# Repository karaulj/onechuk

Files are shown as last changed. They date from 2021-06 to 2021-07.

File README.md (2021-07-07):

# onechuk
A modded-out Nintendo Wii Nunchuk controller with an ESP32 running machine learning (Tensorflow Lite for Microcontrollers) on joystick commands.

The one nunchuk that can do it all: onechuk.

## Main features
- Single RGB LED for readouts
- Multiple action mapping sets
  - Admin (Red): Restart, Enter deep sleep, Get BLE status, accelerometer/joystick debug
  - BLE HID (Green): Pause/Play, Prev/Next Track, Volume Up/Down, Start BLE pairable window
- Built-in LiPo w/ charging unit (charge via micro USB port)
- Automatically enters deep sleep if inactive for 60 seconds to conserve battery
- Wake up from deep sleep by tapping micro USB port

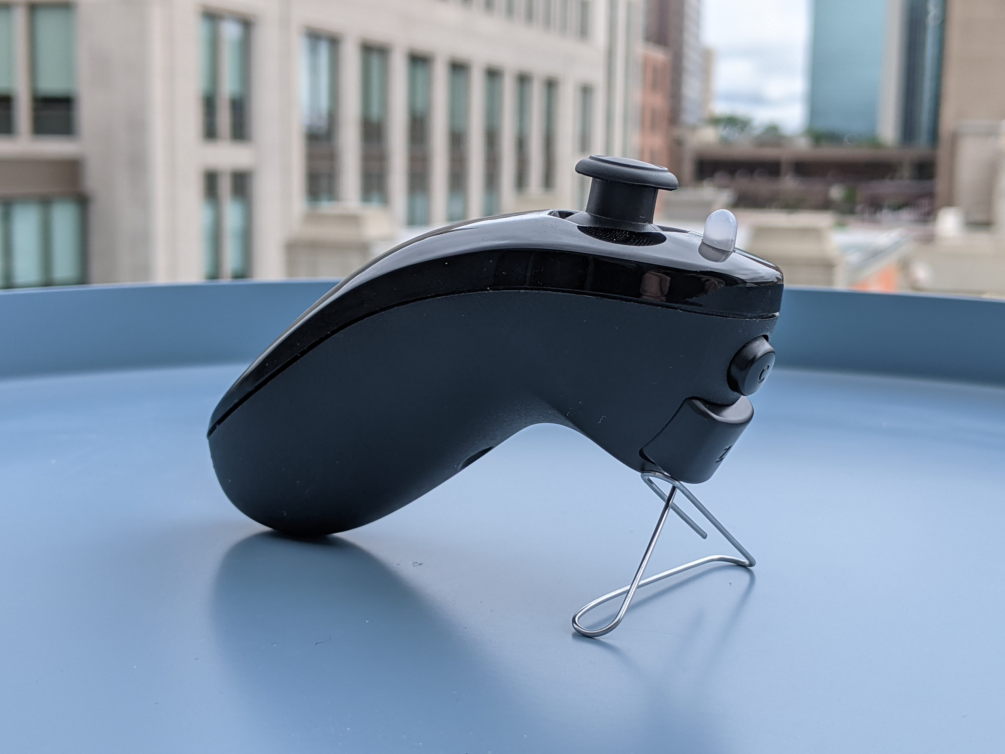
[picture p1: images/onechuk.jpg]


Deep sleep wakeup by tapping micro USB port

## Compiling
This project is built using [ESP-IDF](https://docs.espressif.com/projects/esp-idf/en/latest/esp32/get-started/). You can use the VSCode extension, Eclipse plugin or the typical CLI commands yourself:
```
idf.py build
idf.py -p <port> flash
```

## Overview

### Boot modes
Like a computer, onechuk has multiple boot modes. Also like a computer, you select the boot mode by holding down certain keys at startup.

### Device Mode (Tensorflow)
Device mode is the default boot mode. It allows the user to make joystick commands by holding down the "Z" button and drawing some shape with the joystick. Upon releasing the "Z" button, inference is performed on the drawn shape and if the probability is high enough, the action is executed. The current command can be ignored by pressing the "C" button mid-gesture.

There are multiple action mapping sets allowed, called "device profiles". A device profile is nothing more than a class with a series of logically linked callback functions. The action that gets performed depends on which device profile is active; a circle gesture on the BLE HID device profile will make it pairable, while a circle gesture on the admin profile will restart the ESP32. Same gesture, multiple possible actions.

You can cycle through device profiles by pressing the "C" button.



### Training Mode
Training mode sends raw joystick data over UART to a connected PC. You can boot into training mode by holding down the "C" button during startup. Once the LED flashes orange after the init sequence, training mode has been entered.

#### Collecting training data
Training data collection is made simple by running the `training/collect_training_data.py` script. Make joystick gestures as you normally would (hold down "Z" button and draw) and press "Enter" to delete the last sample. Data is automatically saved to the `training/data` directory when you exit the program. There are some pre-trained gestures:
- Circle
- Left flick
- Right flick
- Up flick
- Down flick
- Center click

I've found that ~200 samples/gesture is more than plenty. By default 25% of the collected data is reserved for validation. This can be modified with the `--pct_test_data` argument.



#### Training the model
The model is trained by running the `training/train_model.py` script. Three model files are written to the `training/output` directory:
- `gesture_model.tflite`: standard TFLite model
- `gesture_model_tflite.cc`: model as C array
- `gesture_model_tflite.h`: header for C array model

The latest model files are automatically copied from the `training/output` directory at compile time. Collect, train, compile, done. The model performs very well, often topping 99% for probability:

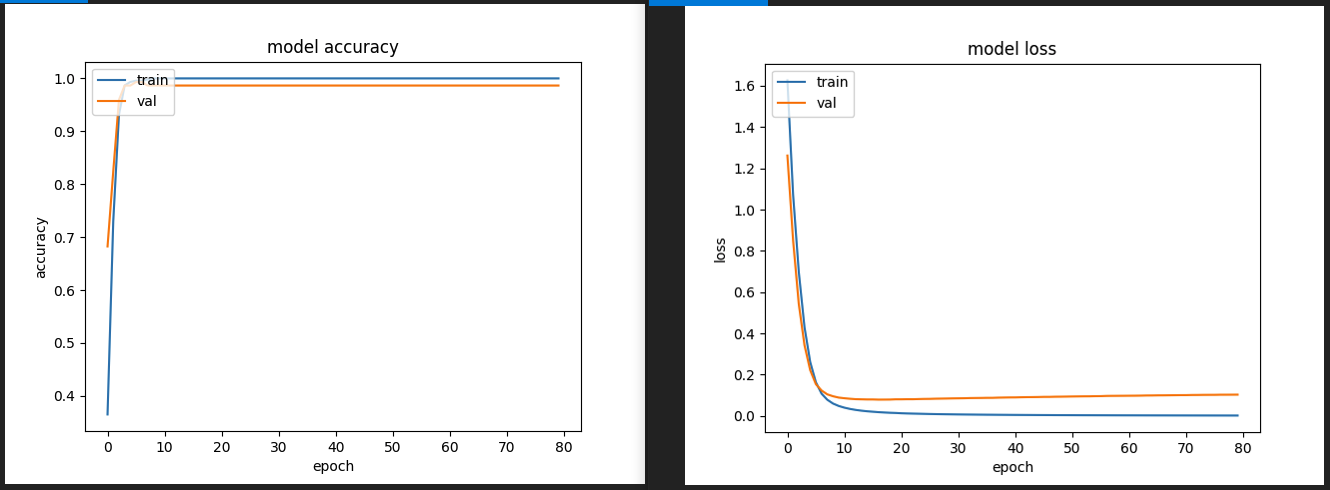
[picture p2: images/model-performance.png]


_**NOTE: The training script uses the xxd unix command to generate the C files and will fail using Windows' Command Prompt.**_ One solution is to use [WSL](https://docs.microsoft.com/en-us/windows/wsl/install-win10) as a shell and install xxd through `sudo apt install xxd`. 

## Construction
The physical construction process is briefly described here.

### Parts List
- [Nunchuk controller](https://www.amazon.com/Nintendo-Nunchuk-Controller-Black-Wii-U/dp/B0094X1ZXU/) (original Nintendo version)
- [TinyPICO Nano](https://www.tinypico.com/tinypico-nano) ESP32 development board
- [400mAh LiPo Battery](https://www.adafruit.com/product/3898) 
- [RGB LED](https://www.amazon.com/EDGELEC-Tri-Color-Multicolor-Diffused-Resistors/dp/B077XGF3YR/) (pack of 100)
- [Micro USB connector](https://www.adafruit.com/product/1829)
- ["Wire Wrap"](https://www.adafruit.com/product/1446)

### CAD
The micro USB port housing is a friction-fit 3D-printed piece. Use CA to glue the micro USB connector to the housing, then friction-fit the housing into the nunchuk. If CA gets on the front of the connector and prevents touches from registering, lightly scrape it off with an exacto knife.

CAD files can be found in the `CAD` folder.

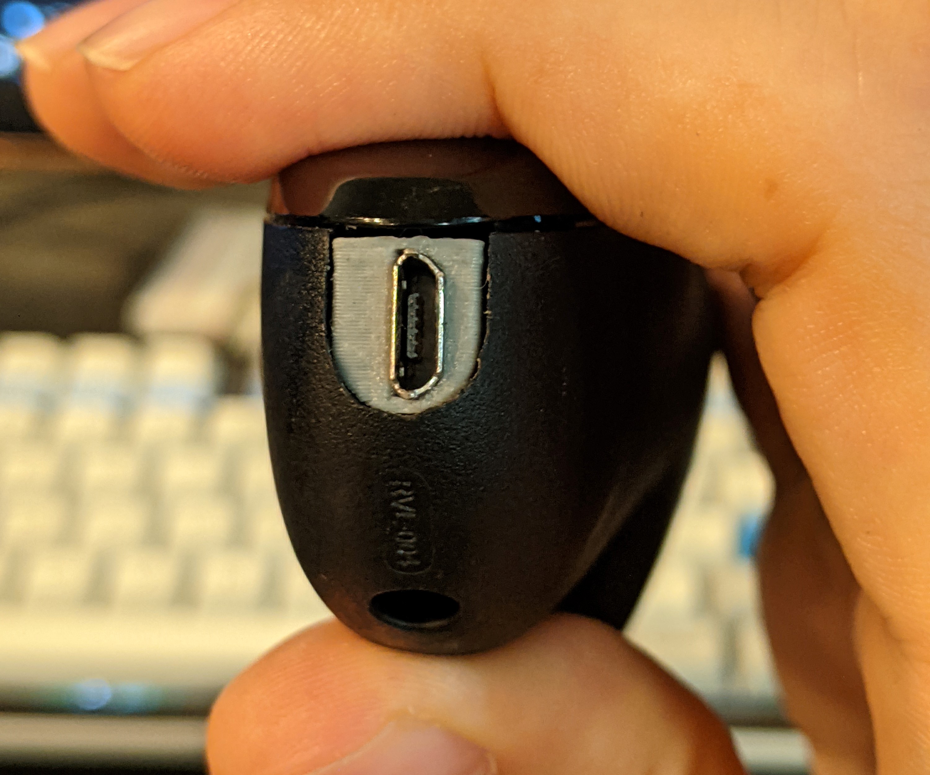
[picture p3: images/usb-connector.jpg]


### Original vs. knockoff nunchuks
Initially I planned on using a cheap nunchuk clone instead of one sold by Nintendo, given their outrageous prices. It became clear that the analog joystick quality on the cheap knockoff was so poor that data couldn't be shared between a knockoff and an original nunchuk, at which point I broke down and got an original. All data collected using an original, Nintendo, "real" nunchuk is prefixed with an "r", in case I decide to go back and collect gesture data using a "fake" nunchuk at some point.

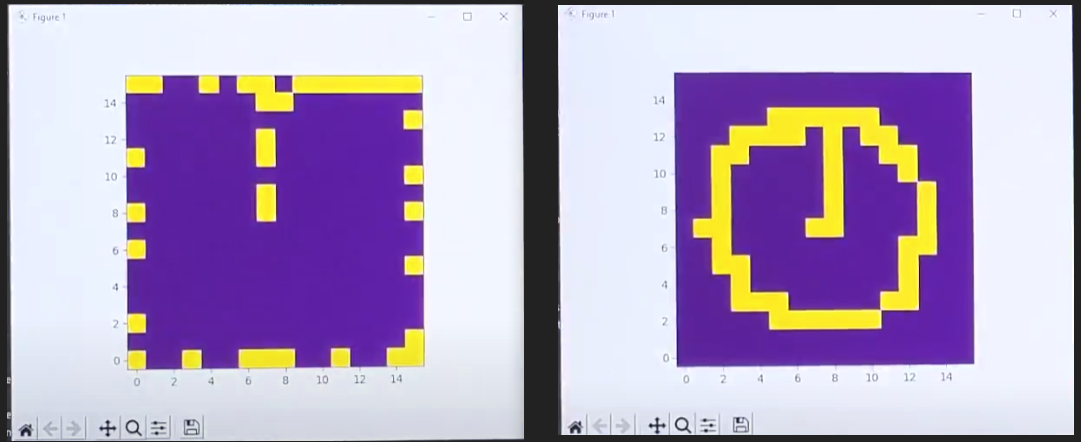
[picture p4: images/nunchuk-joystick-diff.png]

The circle gesture on knockoff (left) vs. original (right) nunchuks

### Fitting everything in
Nunchuks can have a decent amount of interior space if you clear out the excess support material. This can be done with a pair of flush cutters and some high-grit sandpaper:

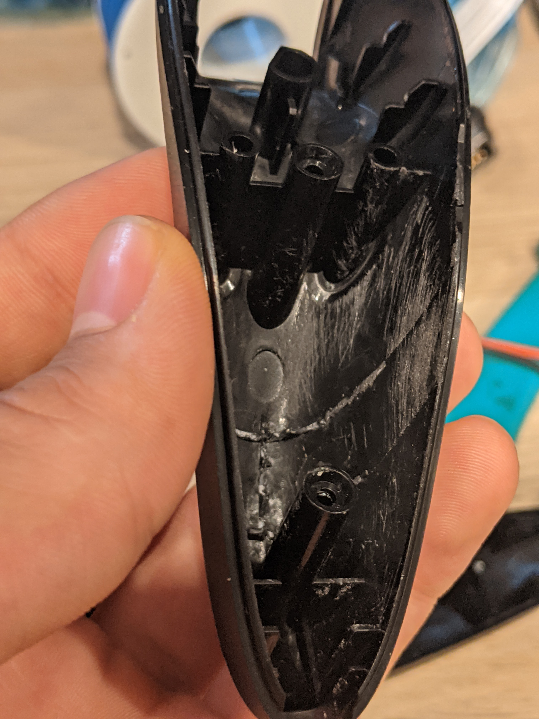
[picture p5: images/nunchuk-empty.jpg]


Then it's just a matter of soldering and assembly:

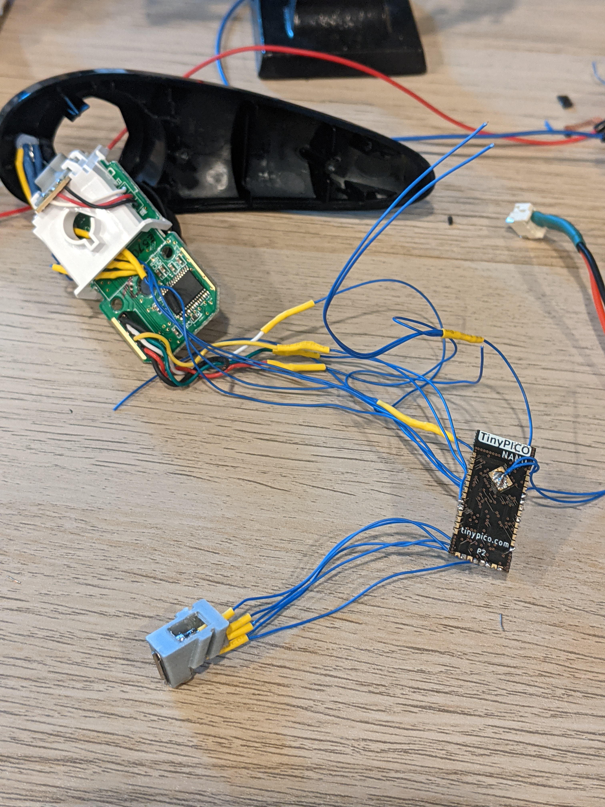
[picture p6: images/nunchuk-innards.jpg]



## Acknowledgements
Inspired by https://github.com/jakkra/Gesture-Detecting-Macro-Keyboard. Some code (especially for training) is modified and reused.

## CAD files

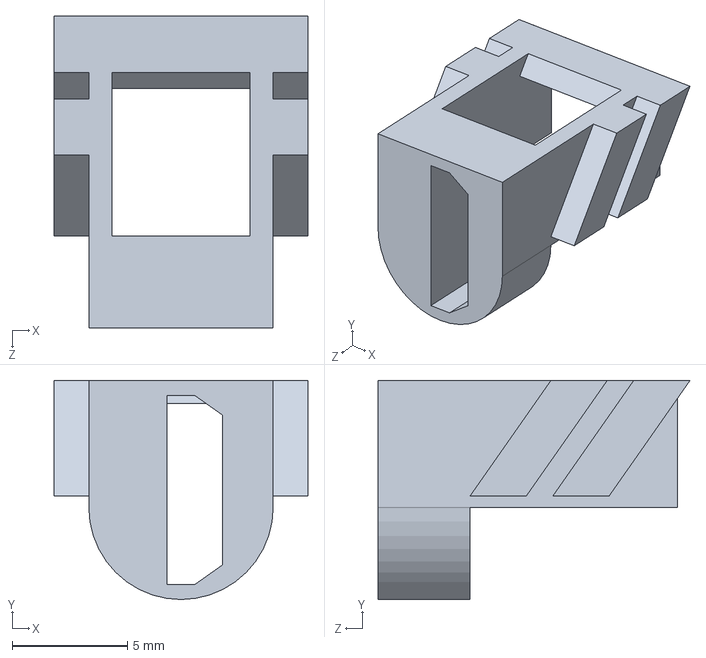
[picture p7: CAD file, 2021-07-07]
CAD/nunchuk_usb_housing.SLDPRT
11.0 x 9.50 x 13.5 mm

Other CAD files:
CAD/nunchuk_usb_housing.STL

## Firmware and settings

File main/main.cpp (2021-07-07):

/*
 * main.cpp
 * 
 *  Onechuk main program file.
 *
 *  Created on: Jun 11, 2021
 *      Author: Jacob
 */

#include "settings.h"
#include "tasks.h"
#include "queues.h"

#include <stdio.h>
#include "sdkconfig.h"
#include "freertos/FreeRTOS.h"
#include "freertos/task.h"
#include "freertos/queue.h"
#include "esp_log.h"
// i2c
#include "hal/gpio_types.h"
#include "hal/i2c_types.h"
#include "driver/i2c.h"
// ble
#include "ble_utils.h"
// touch/sleep
#include "driver/touch_pad.h"
#include "esp_sleep.h"
// main components
#include "NunchukController.h"
#include "RGB_CC_LED.h"
#include "TinyPICO.h"
#include "rgb_commands.h"
#include "BLE_HID.h"

static const char *TAG = "main";

extern "C" void app_main(void);


static void i2cInit()
{
    i2c_config_t i2cConfig;
	i2cConfig.mode = I2C_MODE_MASTER;
	i2cConfig.scl_io_num = I2C_SCL_PIN;
	i2cConfig.sda_io_num = I2C_SDA_PIN;
	i2cConfig.scl_pullup_en = GPIO_PULLUP_ENABLE;
	i2cConfig.sda_pullup_en = GPIO_PULLUP_ENABLE;
	i2cConfig.clk_flags = 0;
	i2cConfig.master.clk_speed = I2C_FREQ_HZ;
	ESP_ERROR_CHECK(i2c_param_config(I2C_PORT_NUM, &i2cConfig));
	ESP_ERROR_CHECK(i2c_driver_install(I2C_PORT_NUM, I2C_MODE_MASTER, 0, 0, 0));
}


static void touchInit()
{
    ESP_ERROR_CHECK(touch_pad_init());
    ESP_ERROR_CHECK(touch_pad_set_fsm_mode(TOUCH_FSM_MODE_TIMER));

    // from ESP IDF deep sleep example
    // Set reference voltage for charging/discharging
    // In this case, the high reference valtage will be 2.4V - 1V = 1.4V
    // The low reference voltage will be 0.5
    // The larger the range, the larger the pulse count value.
    ESP_ERROR_CHECK(touch_pad_set_voltage(TOUCH_HVOLT_2V4, TOUCH_LVOLT_0V5, TOUCH_HVOLT_ATTEN_1V));
    ESP_ERROR_CHECK(touch_pad_config(DEEP_SLEEP_TOUCH_PAD_NUM, 0));

    // calibrate touch pad - don't touch during init
    int avg = 0;
    const size_t calibration_count = 128;
    for (int i = 0; i < calibration_count; ++i) {
        uint16_t val;
        touch_pad_read(DEEP_SLEEP_TOUCH_PAD_NUM, &val);
        avg += val;
    }
    avg /= calibration_count;
    const int min_reading = 300;
    if (avg < min_reading) {
        ESP_LOGW(TAG, "Touch pad #%d average reading too low for deep sleep setup: %d",
            DEEP_SLEEP_TOUCH_PAD_NUM, avg
        );
        ESP_ERROR_CHECK(touch_pad_config(DEEP_SLEEP_TOUCH_PAD_NUM, 0));
    } else {
        int threshold = avg - 100;
        ESP_LOGI(TAG, "Touch pad #%d threshold set to %d", DEEP_SLEEP_TOUCH_PAD_NUM, threshold);
        ESP_ERROR_CHECK(touch_pad_config(DEEP_SLEEP_TOUCH_PAD_NUM, threshold));
    }
    ESP_ERROR_CHECK(esp_sleep_enable_touchpad_wakeup());
    ESP_ERROR_CHECK(esp_sleep_pd_config(ESP_PD_DOMAIN_RTC_PERIPH, ESP_PD_OPTION_ON));
}


void app_main(void)
{
    /*
     *  SYSTEM INIT
     */
    // queues - init done at compile time, check status now
    queuesCheck();

    // peripherals init - configure in settings.h
	i2cInit();
    touchInit();

    // main component classes init
    TinyPICO* tinypico = TinyPICO::getInstance();
    RGB_CC_LED mainLED = RGB_CC_LED(R_PIN, G_PIN, B_PIN);
    NunchukController* nunchuk = NunchukController::getInstance(I2C_PORT_NUM);

    // get init params from nunchuk buttons
    nunchuk->fetchLatestReadings();
    uint8_t cButtonPressed = nunchuk->getCButton();
    uint8_t zButtonPressed = nunchuk->getZButton();
    enum task_init_t {
        INIT_MODE_NULL,
        INIT_MODE_TRAINING,
        INIT_MODE_DEVICE
    } initType;
    if (cButtonPressed && !zButtonPressed) {            // C-button: training mode
        ESP_LOGI(TAG, "TRAINING mode selected");
        initType = INIT_MODE_TRAINING;
    } else if (!cButtonPressed && !zButtonPressed) {    // default: device mode
        ESP_LOGI(TAG, "DEVICE mode selected");
        initType = INIT_MODE_DEVICE;
    } else {
        ESP_LOGI(TAG, "no mode selected");
        initType = INIT_MODE_NULL;
    }

    // system init cplt
    xQueueSend(ledCmdQueue, (void*)&RGB_CMD_INIT, 1/portTICK_PERIOD_MS);


    /*
     *  TASKS INIT
     */
    // basic I/O tasks
    xTaskCreate(&touchDeepSleepTask, TOUCH_DEEP_SLEEP_TASK, 2048,
        NULL, tskIDLE_PRIORITY, &touchDeepSleepTaskHandle);
    xTaskCreate(&ledCmdTask, LED_CMD_TASK, 2048,
        (void*)&mainLED, tskIDLE_PRIORITY, &ledCmdTaskHandle);  // min priority
    xTaskCreate(&nunchukReadTask, NUNCHUK_READ_TASK, 4096,
        NULL, tskIDLE_PRIORITY, &nunchukReadTaskHandle);        // min priority
    
    switch (initType) {

    // training mode sends joystick values over serial if Z button pressed
    case INIT_MODE_TRAINING:
        xQueueSend(ledCmdQueue, (void*)&RGB_CMD_TRAINING_MODE, 1/portTICK_PERIOD_MS);
        xTaskCreate(&trainingModeTask, TRAINING_MODE_TASK, 4096,
            NULL, 12, &trainingModeTaskHandle);                 // med priority
        break;

    // device mode (default) performs actions from joystick gesture commands
    case INIT_MODE_DEVICE:
        bleInit();
        xQueueSend(ledCmdQueue, (void*)&RGB_CMD_DEVICE_MODE, 1/portTICK_PERIOD_MS);
        xTaskCreate(&joystickCmdTask, JOYSTICK_CMD_TASK, 4096,
            NULL, 12, &joystickCmdTaskHandle);	                // med priority
        xTaskCreate(&joystickInferenceTask, JOYSTICK_INFERENCE_TASK, 65536,
            NULL, 24, &joystickInferenceTaskHandle);	        // max priority
        break;

    case INIT_MODE_NULL:
        break;
    }


    // Run Forrest, run
    while(true)
    {
        vTaskDelay(1000 / portTICK_PERIOD_MS);
    }
}

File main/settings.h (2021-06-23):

/*
 * settings.h
 * 
 *  All relevant user settings.
 *
 *  Created on: Jun 11, 2021
 *      Author: Jacob
 */

#ifndef MAIN_SETTINGS_H_
#define MAIN_SETTINGS_H_

#include "freertos/FreeRTOS.h"
#include "driver/touch_pad.h"


// I2C
#define I2C_SDA_PIN                 21
#define I2C_SCL_PIN                 22
#define I2C_FREQ_HZ                 100000
#define I2C_PORT_NUM                0

// nunchuk
#if configTICK_RATE_HZ > 100
#define NUNCHUK_READ_RATE_HZ        500
#else
#define NUNCHUK_READ_RATE_HZ        100
#endif

// RGB LED
#define R_PIN                       25
#define G_PIN                       26
#define B_PIN                       27

// touch
#define DEEP_SLEEP_TOUCH_PAD_NUM    TOUCH_PAD_NUM6
#define DEEP_SLEEP_DELAY_SEC        60

// TF Lite Micro
#define INPUT_SHAPE_DIM             16
#define INPUT_PRESCALER             16      // INPUT_SHAPE_DIM*INPUT_PRESCALER = 256


#endif /* MAIN_SETTINGS_H_ */

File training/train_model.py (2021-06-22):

import tensorflow as tf
import numpy as np
from tensorflow.keras.utils import to_categorical
#from tensorflow import keras
from tensorflow.keras.models import Sequential
from tensorflow.keras.layers import Input
from tensorflow.keras.layers import Conv2D
from tensorflow.keras.layers import MaxPooling2D
from tensorflow.keras.layers import Dense
from tensorflow.keras.layers import Flatten
#from keras.optimizers import SGD
from tensorflow.keras.optimizers import SGD

from matplotlib import pyplot as plt
import os
from pathlib import Path
import argparse


INPUT_DIM = 16


train_dir = os.path.dirname(os.path.realpath(__file__)) + "/data"
output_dir = os.path.dirname(os.path.realpath(__file__)) + "/output"


def create_img_from_line(line):
	line = line.replace(' ', '')
	line = line.replace('\'', '')
	line = line.replace('"', '')
	line = line.replace('[', '')
	line = line.replace(']', '')
	line = line.replace('\n', '')
	line = line.split(',')
	img = np.zeros((INPUT_DIM, INPUT_DIM))
	for i in range(0, len(line), 2):
		img[max(0, int(line[i + 1]) - 1), max(0, int(line[i]) - 1)] = 1
	
	
	img = img.reshape(1, INPUT_DIM, INPUT_DIM, 1)
	img = img.astype('float32')
	return img

def load_manual_dataset():
	files = os.listdir(train_dir)
	num_gestures = len(files) / 2
	print("Found files {0} => {1} gestures".format(files, num_gestures))
	trainX = []
	testX = []
	trainY = []
	testY = []
	file_index = 0
	gestures = {}

	# Assumes the train/test data folder is not modified by user.
	# It should be generated using collect_train_data.py
	for file_name in files:
		gesture_name = file_name.split('.')[0]
		if (gesture_name not in gestures):
			gestures[gesture_name] = len(gestures)

		gesture_id = gestures[gesture_name]

		if (file_name.endswith('.train')):
			train_file = open(train_dir + '/' + file_name, "r")
			train_lines = train_file.readlines()

			for line in train_lines:
				trainX.append(create_img_from_line(line))
				trainY.append(gesture_id)

		elif file_name.endswith('.test'):
			test_file = open(train_dir + '/' + file_name, "r")
			test_lines = test_file.readlines()

			for line in test_lines:
				testX.append(create_img_from_line(line))
				testY.append(gesture_id)
		
	trainX = np.array(trainX)
	trainY = np.array(trainY)
	testX = np.array(testX)
	testY = np.array(testY)

	trainX = trainX.reshape((trainX.shape[0], INPUT_DIM, INPUT_DIM, 1))
	testX = testX.reshape((testX.shape[0], INPUT_DIM, INPUT_DIM, 1))
	
	print('Done creating test and train matrices')
	print(len(testX), len(testY))
	print(len(trainX), len(trainY))
	print(gestures)

	trainY = to_categorical(trainY)
	testY = to_categorical(testY)
	return trainX, trainY, testX, testY, gestures

# define CNN model
def define_model(num_gestures):
	model = Sequential()
	model.add(Input(shape=(INPUT_DIM, INPUT_DIM, 1)))
	model.add(Conv2D(8, (3, 3), activation='relu', kernel_initializer='he_uniform'))
	model.add(MaxPooling2D((2, 2)))
	model.add(Conv2D(16, (3, 3), activation='relu', kernel_initializer='he_uniform'))
	#model.add(Conv2D(16, (3, 3), activation='relu', kernel_initializer='he_uniform'))
	model.add(MaxPooling2D((2, 2)))
	model.add(Flatten())
	model.add(Dense(16, activation='relu', kernel_initializer='he_uniform'))
	model.add(Dense(num_gestures, activation='softmax'))
	# compile model
	opt = SGD(lr=0.001, momentum=0.9) # TODO Experiment with lr if needed, does not look like it right now
	model.summary()
	model.compile(optimizer=opt, loss='categorical_crossentropy', metrics=['accuracy'])
	return model
 
if __name__ == "__main__":
	parser = argparse.ArgumentParser(description='Create and store training data')
	
	args = parser.parse_args()
	# Create folder for the generated files
	Path(output_dir).mkdir(parents=True, exist_ok=True)
	print('create', output_dir)
	trainX, trainY, testX, testY, gesture_map = load_manual_dataset()
	print('Loaded train data shape is {0} and test data shape is {1}'.format(trainX.shape, testX.shape))

	# define model
	model = define_model(len(gesture_map))
	#model.load_weights('good_model_weights.h5')
	# fit model
	history = model.fit(trainX, trainY, epochs=80, batch_size=10, verbose=1, validation_data=(testX, testY))
	model.save_weights('good_model_weights.h5')

	plt.plot(history.history['accuracy'])
	plt.plot(history.history['val_accuracy'])
	plt.title('model accuracy')
	plt.ylabel('accuracy')
	plt.xlabel('epoch')
	plt.legend(['train', 'val'], loc='upper left')

	plt.figure()
	plt.plot(history.history['loss'])
	plt.plot(history.history['val_loss'])
	plt.title('model loss')
	plt.ylabel('loss')
	plt.xlabel('epoch')
	plt.legend(['train', 'val'], loc='upper left')
	plt.show()
	# save model
	model.save(output_dir + '/tf_gesture_model.h5')

	# Convert the model to Tensorflow Lite format.
	converter = tf.lite.TFLiteConverter.from_keras_model(model)
	tflite_model = converter.convert()

	# Save the model.
	with open(output_dir + '/gesture_model.tflite', 'wb') as f:
		f.write(tflite_model)
	
	# Convert to C++ file
	#print("xxd -i {0}/gesture_model.tflite > {0}/gesture_model_tflite.cc".format(output_dir))
	res = os.system("xxd -i {0}/gesture_model.tflite > {0}/gesture_model_tflite.cc".format(output_dir))
	#input() # command had to be manually entered, Enter resumes program
    
	# Rename the model, xxd gives it a name that contains the directory path also make the model const
	cppModelFileContentLines = []
	with open(output_dir + '/gesture_model_tflite.cc', 'r') as f:
		cppModelFileContentLines = f.readlines()
	os.remove(output_dir + '/gesture_model_tflite.cc') # Remove original c++ model
	cppModelFileContentLines[0] = 'const unsigned char gesture_model_tflite_data[] = {\n' # rename the large byte array containing the model
	cppModelFileContentLines.insert(0, '#include "gesture_model_tflite.h"\n')
	with open(output_dir + '/gesture_model_tflite.cc', 'w') as f: # create the fixed c++ model
		f.writelines(cppModelFileContentLines)
	
	# Create header file to access generated model
	# Append to the header file the map between TF result and the actual gesture
	with open(output_dir + '/gesture_model_tflite.h', 'w') as f:
		f.write('/*\nThis is a automatically generated TensorFlow Lite model by train_model.py, see README.md for more info.\nIt is converted into a C data array using xxd and is defined in gesture_model_tflite.cc\n*/\n')
		f.write('#ifndef TENSORFLOW_LITE_GESTURE_MODEL_H_\n')
		f.write('#define TENSORFLOW_LITE_GESTURE_MODEL_H_\n')

		f.write('extern const unsigned char gesture_model_tflite_data[];\n')

		# Generate enum with all labels
		f.write('\ntypedef enum gesture_label_t \n{\n')
		for idx, key in enumerate(gesture_map.keys()):
			f.write('\tLABEL_{0} = {1},\n'.format(key.upper(), idx))
		f.write('\tLABEL_END\n')
		f.write('} gesture_label_t;\n')

		f.write('\n')
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

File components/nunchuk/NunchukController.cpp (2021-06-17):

/*
 * NunchukController.cpp
 *
 *  Created on: Jun 11, 2021
 *      Author: Jacob
 */

#include "NunchukController.h"

#include <stdio.h>

#include "driver/i2c.h"
#include "hal/i2c_types.h"
#include "esp_log.h"
#include "esp_err.h"

static const char *TAG = "NunchukController";

// for nunchuk I2C data 
static volatile uint8_t nunchukBuffer[NUNCHUK_CONTROLLER_BUFFER_SZ];


NunchukController* NunchukController::nunchuk = nullptr;


NunchukController* NunchukController::getInstance(i2c_port_t i2cPort, uint8_t i2cAddr)
{
	if (nunchuk == nullptr)
	{
		nunchuk = new NunchukController(i2cPort, i2cAddr);
	}
	return nunchuk;
}


NunchukController::NunchukController(i2c_port_t i2cPort, uint8_t i2cAddr
    ) : port(i2cPort), addr(i2cAddr)
{
    // initialize, disable encryption
    i2c_cmd_handle_t cmd = i2c_cmd_link_create();
    i2c_master_start(cmd);
    i2c_master_write_byte(cmd, (addr<<1) | I2C_MASTER_WRITE, true);
    i2c_master_write_byte(cmd, 0xF0, true);
    i2c_master_write_byte(cmd, 0x55, true);
    i2c_master_write_byte(cmd, 0xFB, true);
    i2c_master_write_byte(cmd, 0x00, true);
    i2c_master_stop(cmd);
    i2c_master_cmd_begin(port, cmd, 10/portTICK_PERIOD_MS);
    i2c_cmd_link_delete(cmd);

    // fetch once
    fetchLatestReadings();

    ESP_LOGI(TAG, "initialized with port=%d, addr=0x%X", (int)port, (int)addr);
}


/*
 *  can get ~500 readings/sec if FreeRTOS tick rate is set to 1000Hz
 *  only ~100 readings/sec at 100Hz
 */ 
void NunchukController::fetchLatestReadings()
{
    // get data frame
    i2c_cmd_handle_t cmd = i2c_cmd_link_create();
    i2c_master_start(cmd);
    i2c_master_write_byte(cmd, (addr<<1) | I2C_MASTER_READ, true);
    i2c_master_read(cmd, (uint8_t*)&nunchukBuffer[0], NUNCHUK_CONTROLLER_BUFFER_SZ-1, I2C_MASTER_ACK);
    // NACK on last byte
    i2c_master_read_byte(cmd, (uint8_t*)&nunchukBuffer[NUNCHUK_CONTROLLER_BUFFER_SZ-1], I2C_MASTER_NACK);
    i2c_master_stop(cmd);
    esp_err_t ret = i2c_master_cmd_begin(port, cmd, 1/portTICK_PERIOD_MS);
    i2c_cmd_link_delete(cmd);

    // extract and store
    if (ret == ESP_OK) {
        btnAccelByte = nunchukBuffer[NUNCHUK_CONTROLLER_BTN_ACCEL_IDX];
        joystickX = nunchukBuffer[NUNCHUK_CONTROLLER_JOYSTICK_X_IDX];
        joystickY = nunchukBuffer[NUNCHUK_CONTROLLER_JOYSTICK_Y_IDX];
        accelX = (uint16_t)((nunchukBuffer[NUNCHUK_CONTROLLER_ACCEL_X_IDX] << 2) | 
                        ((btnAccelByte & 0b11000000) >> 6));
        accelY = (uint16_t)((nunchukBuffer[NUNCHUK_CONTROLLER_ACCEL_Y_IDX] << 2) | 
                        ((btnAccelByte & 0b00110000) >> 4));
        accelZ = (uint16_t)((nunchukBuffer[NUNCHUK_CONTROLLER_ACCEL_Z_IDX] << 2) | 
                        ((btnAccelByte & 0b00001100) >> 2));
        cButton = (uint8_t)(!((btnAccelByte & 0b10) >> 1));
        zButton = (uint8_t)(!(btnAccelByte & 0b1));
    }
    
    // request for next time
    cmd = i2c_cmd_link_create();
    i2c_master_start(cmd);
    i2c_master_write_byte(cmd, (addr<<1) | I2C_MASTER_WRITE, true);
    i2c_master_write_byte(cmd, 0x00, true);
    i2c_master_stop(cmd);
    i2c_master_cmd_begin(port, cmd, 1/portTICK_PERIOD_MS);
    i2c_cmd_link_delete(cmd);
}


//nunchuk_data_t* NunchukController::getLatestData()  { return &latestNunchukData; }
uint8_t NunchukController::getJoystickX()           { return joystickX; }
uint8_t NunchukController::getJoystickY()           { return joystickY; }
uint16_t NunchukController::getAccelX()             { return accelX; }
uint16_t NunchukController::getAccelY()             { return accelY; }
uint16_t NunchukController::getAccelZ()             { return accelZ; }
uint8_t NunchukController::getCButton()             { return cButton; }
uint8_t NunchukController::getZButton()             { return zButton; }

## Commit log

2021-06-14 added ble device mode support
2021-06-16 fixed training data path name
    [train_model.py]
2021-06-22 custom partition table for app size > 1M
    [partitions.csv]
2021-06-23 moved ble_hid and device_profile to components
2021-06-28 added delay between joystick led fade readings
2021-07-01 added white led animation 10 sec from deep sleep
2021-07-07 fixed ledc deinit before deep sleep
    [RGB_CC_LED.cpp, RGB_CC_LED.h, RedDeviceProfile.cpp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]
2021-07-07 uploaded CAD files
    [nunchuk_usb_housing.SLDPRT, nunchuk_usb_housing.STL]
